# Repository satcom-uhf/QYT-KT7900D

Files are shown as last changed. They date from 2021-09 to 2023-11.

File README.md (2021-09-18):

# QYT KT7900D ([RU](README_RU.md))

Qyt KT7900D is very tiny and cheap radio. Recommended for beginners.



## [Modified software](https://github.com/satcom-uhf/QYT-KT7900D/releases/tag/Software)

## [IOR channels](https://github.com/satcom-uhf/QYT-KT7900D/releases/tag/Channels72E)
## [Remote control adapter](RemoteControl/README.md)

## [Activity indicator](ActivityIndicator/README.md)

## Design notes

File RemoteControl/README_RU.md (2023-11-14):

# Адаптер для удаленного управления QYT-KT7900D ([EN](README.md))

Адаптер позволяет программно нажимать на кнопки передней панели станции через последовательный порт. Это может быть полезно для тесной интеграции с каким-либо сторонним ПО (например Telegram Bot).  Поддерживаемые команды:

- ```+``` "Вверх"
- ```-``` "Вниз"
- ```e``` "Exit/ABCD"
- ```m``` "Menu"
- ```t``` Включает передачу
- ```s``` Выключает передачу

Данного набора команд достаточно чтобы программно изменить большинство настроек станции или выбрать нужный канал (каналы)

### Компоненты

- [Arduino Nano](https://docs.arduino.cc/hardware/nano)
- [PC817 x 4](https://www.farnell.com/datasheets/73758.pdf)
- 4 резистора 220 Ом
- 3 резистора 1К
- тонкие провода
- разьем 7 или 8 пинов
- макетная плата
- Коннектор RJ45 
- какой-нибудь мелкий MOSFET (я взял с дохлой батареи ноута)

### Инструменты

- Паяльник =)
- [Fritzing](https://github.com/fritzing/fritzing-app/releases) чтобы посмотреть файл схемы [RemoteControl.fzz](https://github.com/satcom-uhf/QYT-KT7900D/blob/main/RemoteControl/RemoteControl.fzz)
- [Arduino IDE](https://www.arduino.cc/en/software) чтобы скомпилировать и загрузить скетч [RemoteControl.ino](https://github.com/satcom-uhf/QYT-KT7900D/blob/main/RemoteControl/RemoteControl.ino) в Arduino

## Схема
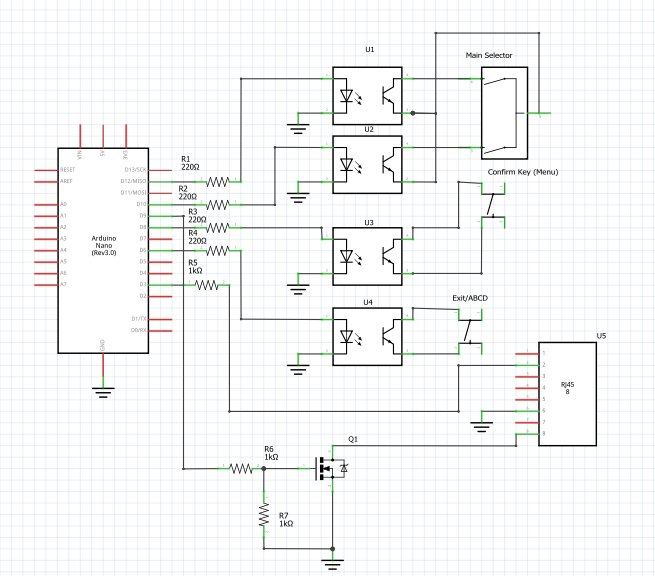
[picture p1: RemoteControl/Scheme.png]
Scheme


### Шаг 1. Смонтируйте и припаяйте все копоненты на плату согласно схеме
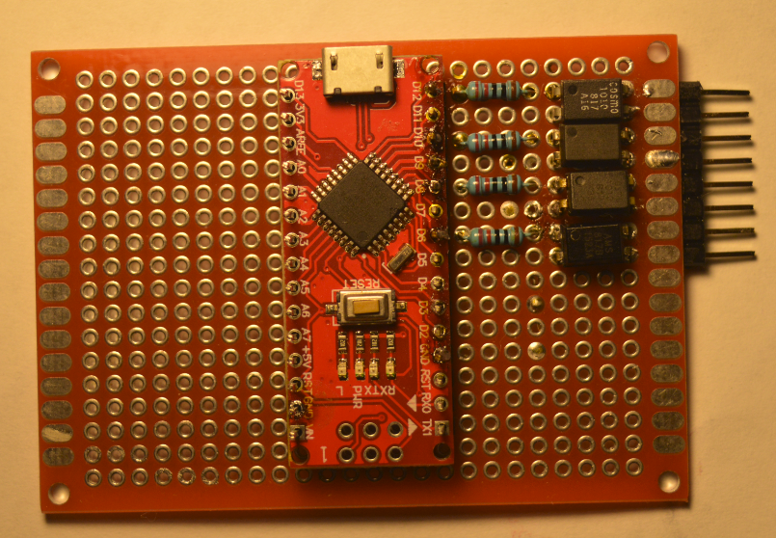
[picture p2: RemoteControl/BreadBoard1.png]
Board1

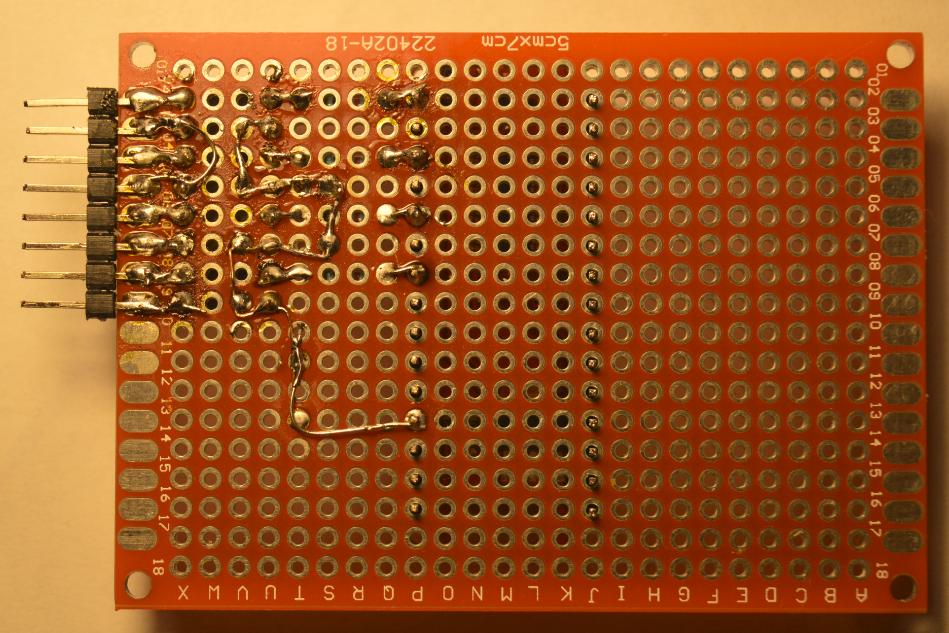
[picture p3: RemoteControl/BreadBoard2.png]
Board2


### Шаг 2. Откройте прошивку  [RemoteControl.ino](https://github.com/satcom-uhf/QYT-KT7900D/blob/main/RemoteControl/RemoteControl.ino) с помощью Arduino IDE и загрузите ее в Arduino Nano
### Шаг 3. Снимите переднюю панель и подключите провода к указанным точкам

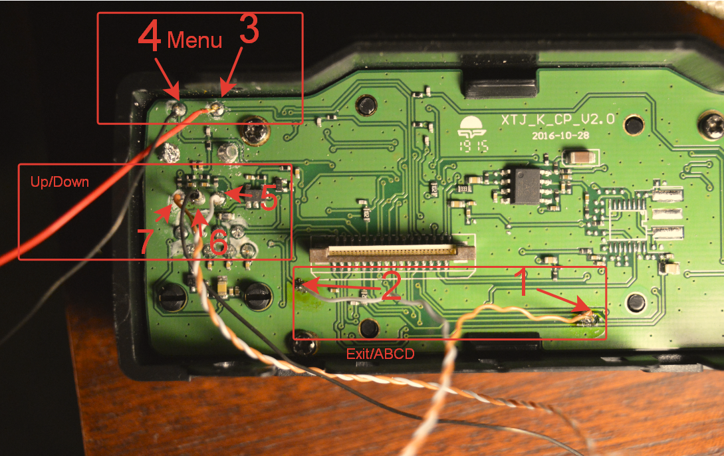
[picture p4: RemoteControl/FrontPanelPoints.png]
ConnectionPoints

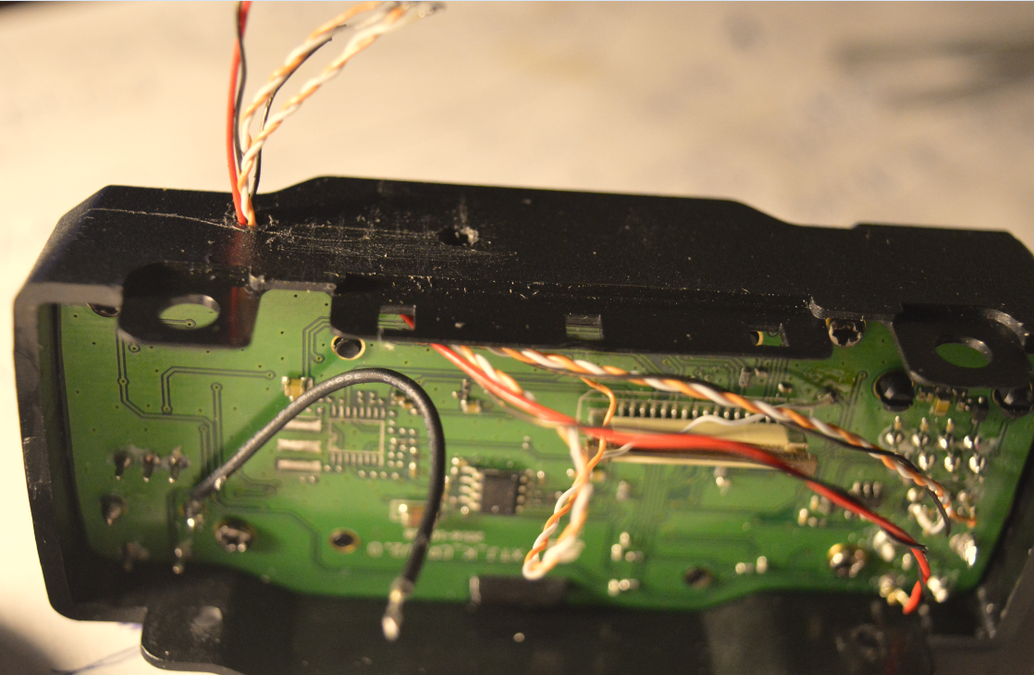
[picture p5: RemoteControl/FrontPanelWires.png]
Wires

### Шаг 4. Приклейте разьем суперклеем
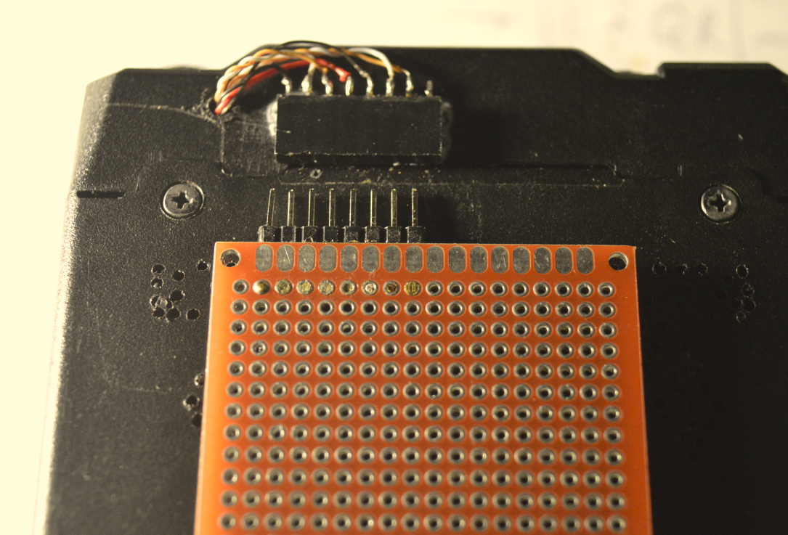
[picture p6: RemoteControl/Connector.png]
Connector


### Шаг 5. Подключите адаптер
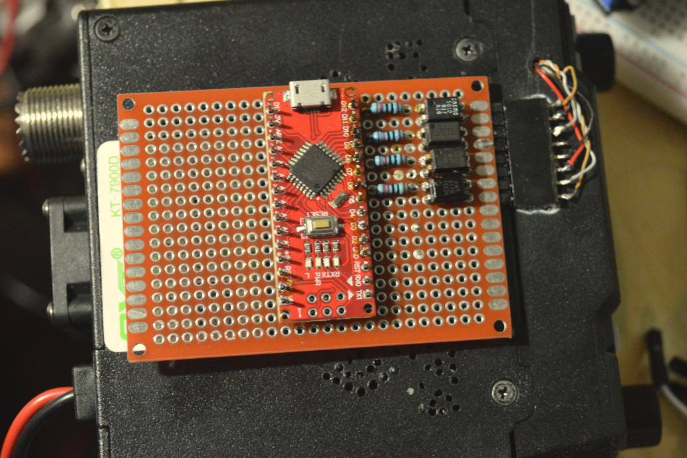
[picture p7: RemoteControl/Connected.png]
Connected

 Готово!

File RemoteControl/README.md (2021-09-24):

# Remote control adapter for QYT-KT7900D ([RU](README_RU.md))

The remote control adapter allows pressing buttons on the front panel programmatically via serial port. It can be useful for deep integration with any kind of software (i.e. Telegram Bot).  The following commands are supported:

- ```+``` is equal to "Up"
- ```-``` is equal to "Down"
- ```e``` is equal to "Exit/ABCD"
- ```m``` is equal to "Menu"
- ```t``` enables PTT (be careful!)
- ```s``` disables PTT

This command set is enough to change the most of settings and select any channels.
### Components required
- [Arduino Nano](https://docs.arduino.cc/hardware/nano)
- [PC817 x 4](https://www.farnell.com/datasheets/73758.pdf)
- 4 resistors 220 Ohms
- 3 resistors 1K
- wires
- connector (7 or 8 pins)
- bread board
- RJ45 connector
- any small MOSFET
  
### Tools required

- Soldering iron =)
- [Fritzing](https://github.com/fritzing/fritzing-app/releases) to view/edit the scheme (RemoteControl.fzz)
- [Arduino IDE](https://www.arduino.cc/en/software) to compile/upload sketch (RemoteControl.ino) to your Arduino board

Scheme

### Step 1. Mount and solder all components on the board
Board1
Board2

### Step 2. Open  RemoteControl.ino using Arduino IDE and upload it to Arduino Nano
### Step 3. Remove the front panel and connect the wires to the following points

ConnectionPoints
Wires
### Step 4. Glue the connector with superglue
Connector

### Step 5. Connect the module
Connected

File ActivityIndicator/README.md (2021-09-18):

# Activity indicator ([RU](README.md))

It's just a LED indicates squelch state. Just use signal from pin 2 and invert it:

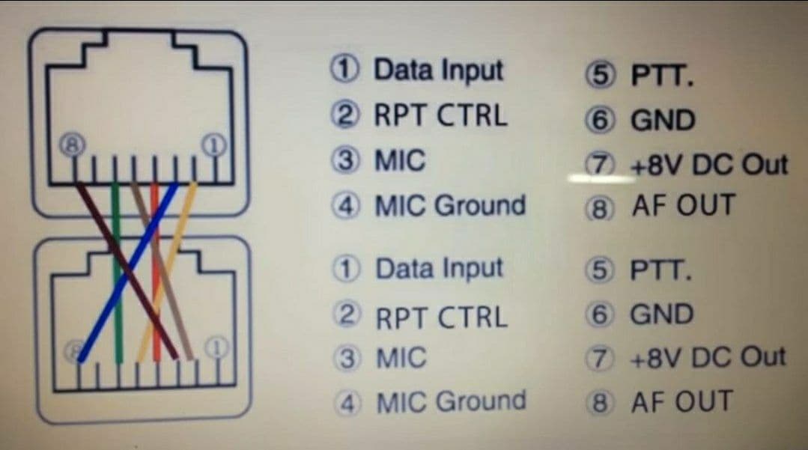
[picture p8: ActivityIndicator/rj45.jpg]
rj45


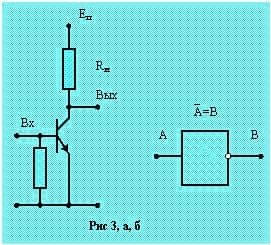
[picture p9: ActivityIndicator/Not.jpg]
not


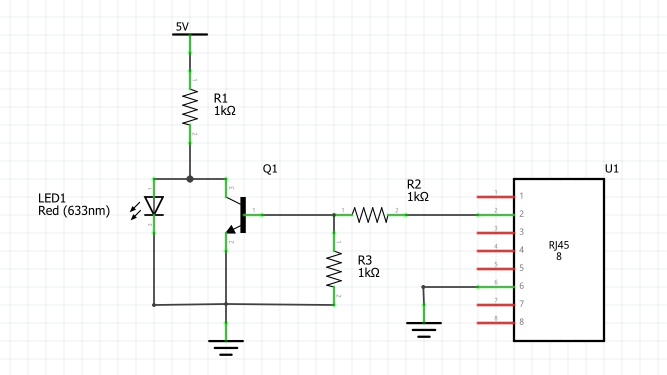
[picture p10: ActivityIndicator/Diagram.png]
diagram


## Components

- NPN transistor (i.e. 2222)
- 3 resistors 1k
- LED

## Step 1

Unmount PTT front panel and drill a hole for LED

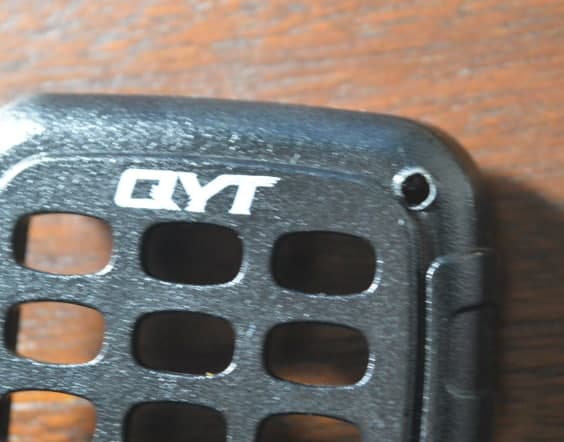
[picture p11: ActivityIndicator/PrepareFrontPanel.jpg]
PrepareFrontPanel


## Step 2

Look for a hidden cut wire from the second pin of RJ45

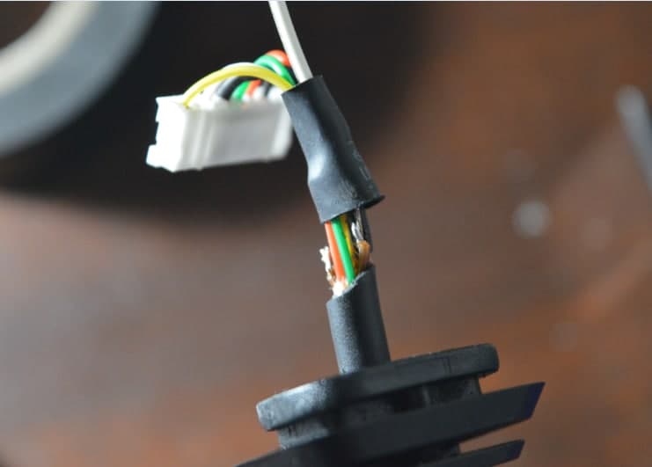
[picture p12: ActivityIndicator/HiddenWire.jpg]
hidden


## Step 3

Make it longer

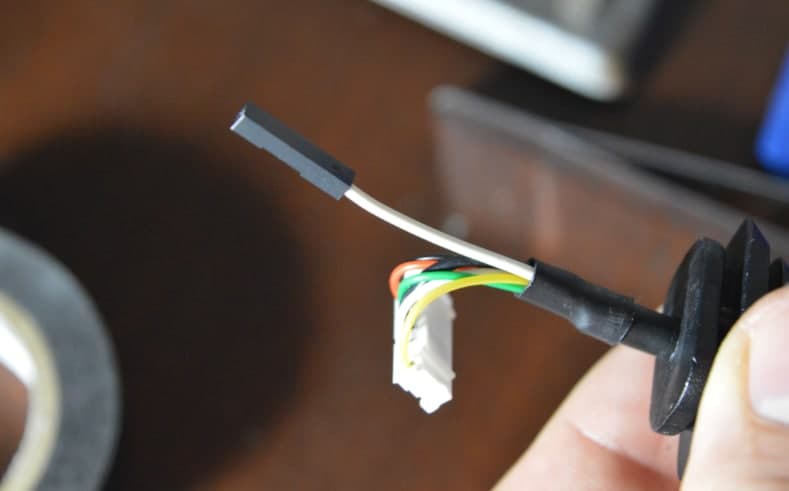
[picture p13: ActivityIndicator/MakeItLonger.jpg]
LongerWire


## Step 4

Mount components

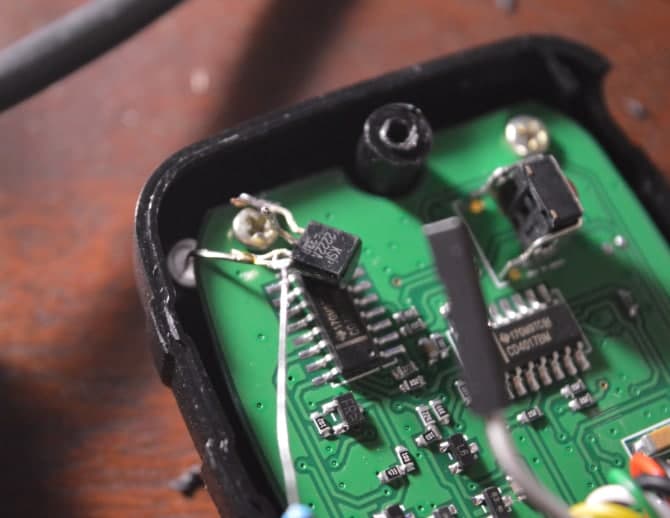
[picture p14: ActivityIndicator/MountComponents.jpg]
components


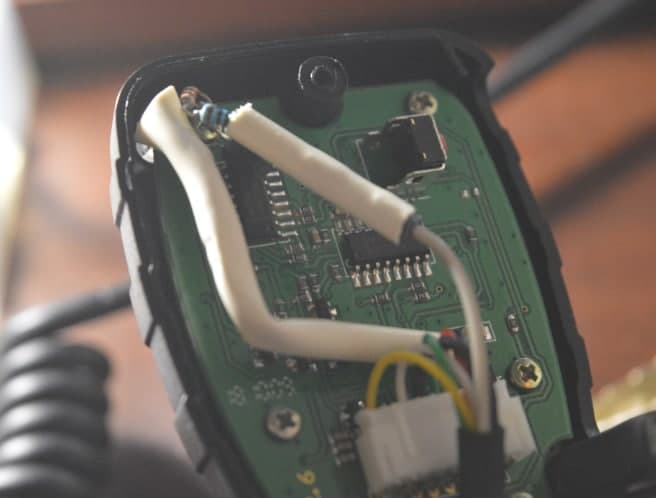
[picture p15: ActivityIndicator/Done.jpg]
done


## Step 5

Enable REP-M mode and test it:

No activity

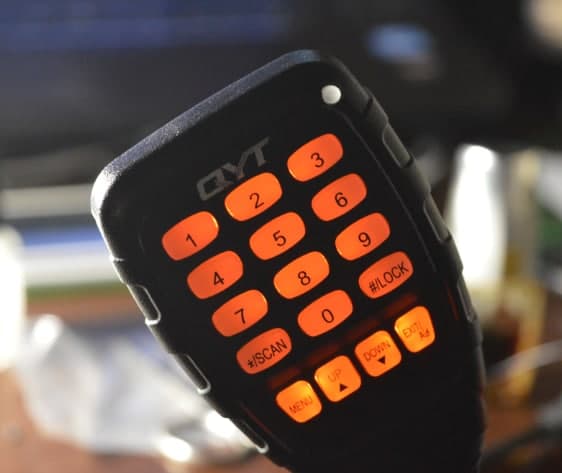
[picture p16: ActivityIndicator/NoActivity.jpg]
No Activity


Someone on the air

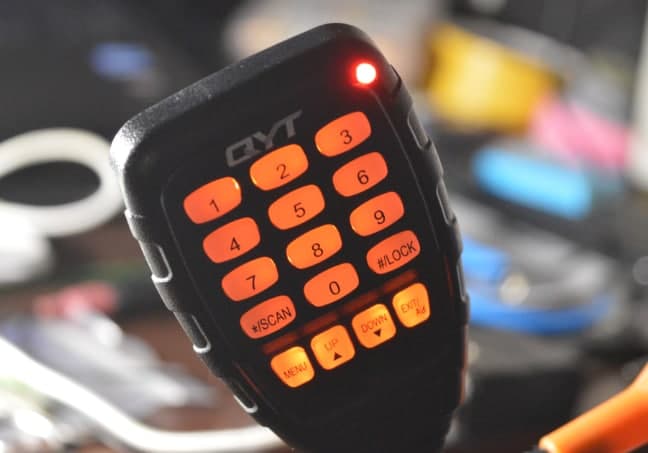
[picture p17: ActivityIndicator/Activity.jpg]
Activity


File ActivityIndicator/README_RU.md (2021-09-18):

# Индикатор активности ([EN](README.md))

Это просто светодиод, который светится при открытии шумодава. Нужно лишь инвертировать сигнал, поступающий со второго пина:

rj45

not

diagram

## Компоненты

- NPN транзистор (i.e. 2222)
- 3 резистора 1К
- светодиод

## Шаг 1

Разберите тангенту и просверлите отверстие для светодиода

PrepareFrontPanel

## Шаг 2

Под термоусадкой найдите скрытый обрезанный провод от пина 2

hidden

## Шаг 3

Удлините провод

LongerWire

## Шаг 4

Смонтируйте компоненты согласно схеме

components

done

## Step 5

В меню станции включите режим REP-M и проверьте работоспособность индикатора:

Шумодав закрыт

No Activity

Активность в эфире, шумодав открыт

Activity

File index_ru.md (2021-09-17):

# QYT KT7900D ([EN](index.md))

Qyt KT7900D маленькое дешевое и простое радио. Отличный вариант для начинающих.



## [Крякнутый софт](https://github.com/satcom-uhf/QYT-KT7900D/releases/tag/Software)

## [Адаптер для удаленного управления](RemoteControl/README_RU.md)

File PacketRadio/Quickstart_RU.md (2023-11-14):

# [Пакетное радио](https://etnowiki.ru/wiki/Packet_radio) на коленке

<video src="https://user-images.githubusercontent.com/90838159/282679990-01b05537-150c-46a9-a750-b3de58aedcb6.mp4" data-canonical-src="https://user-images.githubusercontent.com/90838159/282679990-01b05537-150c-46a9-a750-b3de58aedcb6.mp4" controls="controls" muted="muted" class="d-block rounded-bottom-2 border-top width-fit" style="max-height:640px; min-height: 200px"></video>

В данной статье мы рассмотрим как организовать пакетную связь доступными средствами. Для приема и передачи сигнала будет использован трансивер Qyt KT-7900D. Преобразовывать текст в звуковой сигнал и обратно будет компьютер под управлением Windows.

## Программное обеспечение
- Модем от UZ7HO [SoundModem](http://uz7.ho.ua/modem_beta/soundmodem113.zip) 
- Терминал от UZ7HO [EasyTerm](http://uz7.ho.ua/apps/easyterm49.zip)

## Коммутация между трансивером и ПК
Общая схема приблизительно такая:

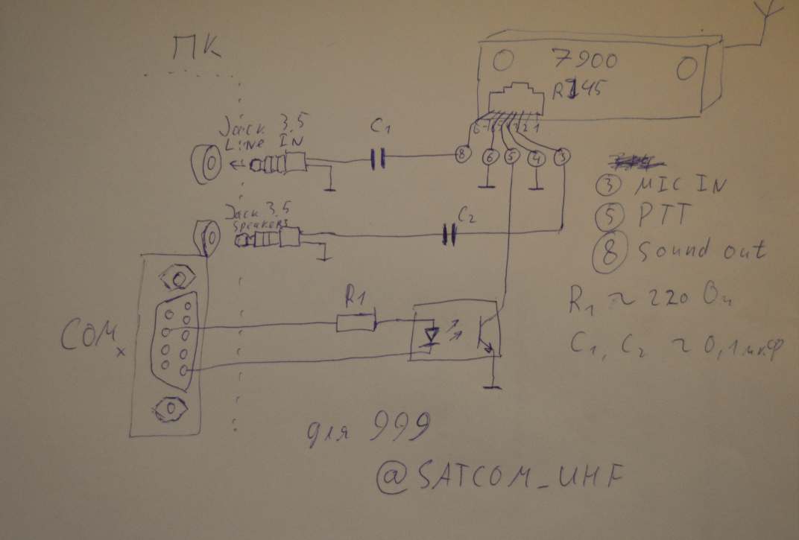
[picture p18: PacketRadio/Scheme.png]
scheme


Звуковой выход трансивера (у Qyt он выведен на 8м пине RJ45) мы подключаем к линейному входу звуковой карты ПК. Звуковой выход компьютера подключаем к микрофонному входу трансивера (у Qyt он выведен на 3й пин RJ45). Для развязки по постоянному применены конденсаторы. Для полной гальванической развязки можно применить трансформаторы.

Простейший способ позволить SoundModem переходить из режима приема в режим передачи - это указать COM-порт, к которому подключен ваш трансивер. SoundModem использует 7й пин (RTS) для активации PTT. В качестве коммутирующего элемента можно использовать оптопару с резистором (как на схеме), или сделать ключ на каком-нибудь MOSFETе. 

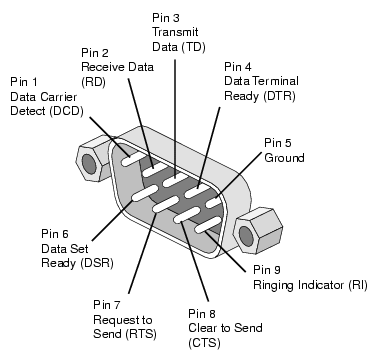
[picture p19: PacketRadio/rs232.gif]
rs232
 

 Если на вашем ПК отсутствует аппаратный COM-порт, вы можете использовать USB-COM переходник.

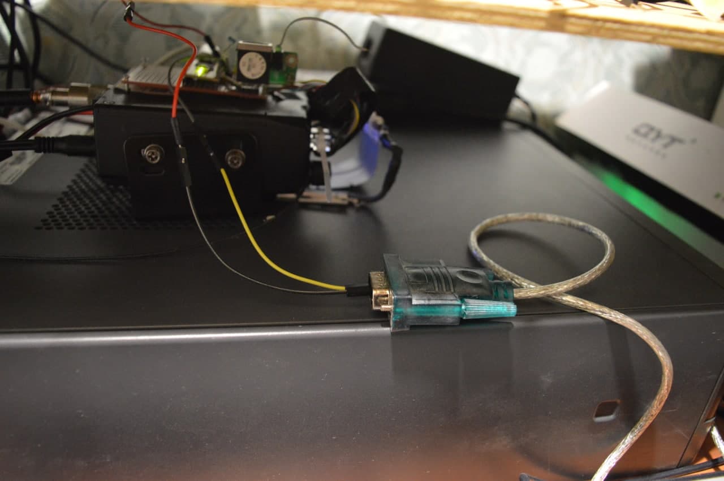
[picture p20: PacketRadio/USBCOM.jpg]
usbcom


## Настройка приемной части

1. Подключите звуковой выход станции к линейному входу ПК. У Qyt есть особенность: чтобы звуковой сигнал появился на пине 8 в меню станции необходимо выбрать пункт REP-M и установить там значение Carrier.
2. Установите линейный вход устройством записи по умолчанию

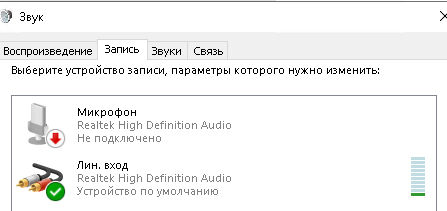
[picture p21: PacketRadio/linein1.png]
line1


3. Настройте уровень сигнала таким образом, чтобы не было "перегруза"

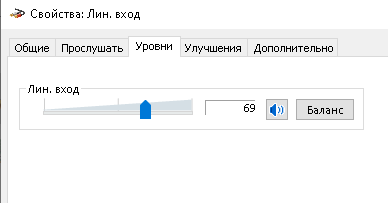
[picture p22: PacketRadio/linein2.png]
line2


4. Распакуйте и запустите [SoundModem](http://uz7.ho.ua/modem_beta/soundmodem113.zip) 
5. Откройте меню настроек Settings->Devices и убедитесь, что для ввода и вывода звука выбраны верные входы и выходы. Также выберите COM порт, к которому подключен ваш трансивер

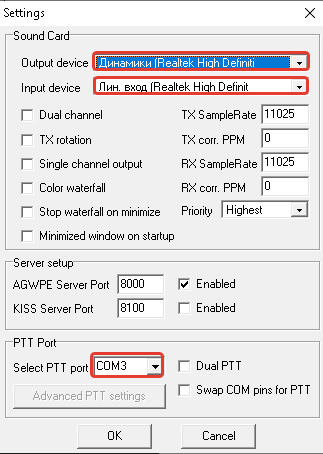
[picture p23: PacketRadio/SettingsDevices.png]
SettingsDevices


6. Убедитесь, что траффик, который вы принимаете от BBS, успешно демодулируется

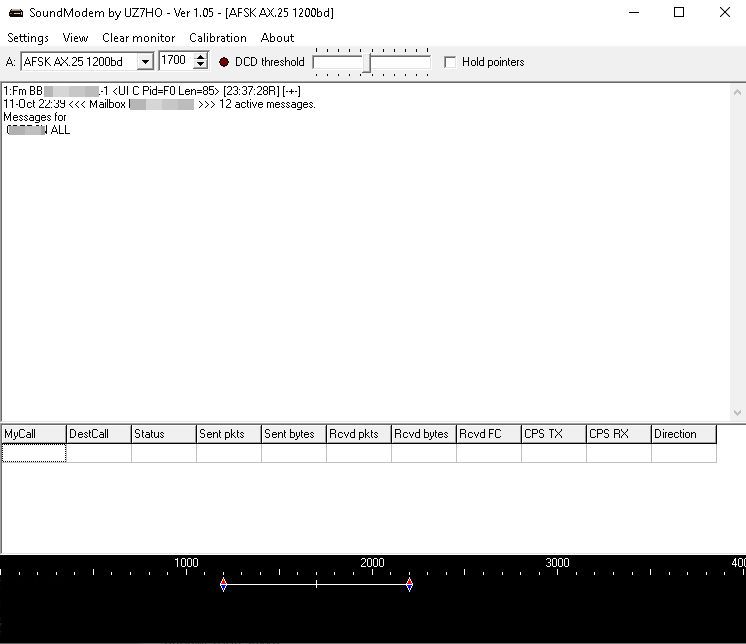
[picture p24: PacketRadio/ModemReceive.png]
Receive


## Настройка передающей части

1. Убедитесь, что звуковой выход ПК подключен к микрофонному входу станции
2. Убедитесь, что SoundModem запущен. В настройках Settings->Modems  рекомендуется установить значение параметра TXDelay таким образом, чтобы компенсировать задержку радиостанции на переход в режим передачи. У меня это значение равно 400.

TXDelay

3. Установите громкость воспроизведения близкой к минимальной
   
   volume

4. Распакуйте и запустите [EasyTerm](http://uz7.ho.ua/apps/easyterm49.zip) В окне терминала нажмите "Connect".
5. В появившемся диалоге укажите ваш позывной и позывной узла, с которым хотите соединиться.Еще раз нажмите "Connect".
   
Connect

6. Вуаля! Дальше вы можете общаться текстовыми командами с узлом, к которому подключились.
   
Connected

## PS

Выражаю огромную благодарность [UZ7HO](http://uz7.ho.ua/packetradio.htm) за труды по созданию ПО для Windows. На его [официальной страничке](http://uz7.ho.ua/packetradio.htm) так же можно скачать ПО для игры в [шахматы](http://uz7.ho.ua/apps/chess10.zip) и [шашки](http://uz7.ho.ua/apps/checkers6.zip).

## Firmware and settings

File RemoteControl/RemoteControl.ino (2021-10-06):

#define VALCODER_UP 12
#define VALCODER_DOWN 10
#define MENU 8
#define ABCD 6
#define PTT 9
#define SQUELCH_OPEN 3
#define EXTERNAL_PTT 7
bool valcoderState = false;
bool extPttState = false;
void setup(void)
{
   pinMode(PTT, OUTPUT);
   digitalWrite(PTT, LOW);
   pinMode(VALCODER_UP, OUTPUT);
   pinMode(VALCODER_DOWN, OUTPUT);
   pinMode(MENU, OUTPUT);
   pinMode(ABCD, OUTPUT);
   Serial.begin(9600);
   pinMode(SQUELCH_OPEN, INPUT);
   pinMode(EXTERNAL_PTT, INPUT);
   attachInterrupt(digitalPinToInterrupt(SQUELCH_OPEN), monitorActivity, CHANGE);
}

void monitorActivity()
{
   if (digitalRead(SQUELCH_OPEN) == LOW)
   {
      digitalWrite(LED_BUILTIN, HIGH);
      Serial.println("activity");
   }
   else
   {
      digitalWrite(LED_BUILTIN, LOW);
      Serial.println("silence");
   }
}

void clickButton(int pin)
{
   digitalWrite(pin, HIGH);
   delay(15);
   digitalWrite(pin, LOW);
}

void valCoderTick(int pin1, int pin2)
{
   valcoderState = !valcoderState;
   digitalWrite(pin1, valcoderState);
   delay(5);
   digitalWrite(pin2, valcoderState);
}

void up()
{
   valCoderTick(VALCODER_DOWN, VALCODER_UP);
}
void down()
{
   valCoderTick(VALCODER_UP, VALCODER_DOWN);
}

void ptt()
{
   digitalWrite(PTT, HIGH);
   Serial.println("PTT");
}
void stopPtt()
{

   digitalWrite(PTT, LOW);
   Serial.println("PTTSTOP");
}

void loop()
{
   byte ch;
   bool extPtt = digitalRead(EXTERNAL_PTT);
   if (extPtt != extPttState)
   {
      extPttState = extPtt;
      if (extPtt)
      {
         ptt();
      }
      else
      {
         stopPtt();
      }
   }

   if (Serial.available())
   {
      ch = Serial.read();
      switch (ch)
      {
      case '+':
         up();
         Serial.println("Up");
         break;
      case '-':
         down();
         Serial.println("Down");
         break;
      case 'e':
         clickButton(ABCD);
         Serial.println("ABCD");
         break;
      case 'm':
         clickButton(MENU);
         Serial.println("MENU");
         break;
      case 't':
         ptt();
         break;
      case 's':
         stopPtt();
         break;
      }
   }
}

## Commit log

2021-09-16 Arduino sketch
2021-09-16 Readme rus
    [RemoteControl.fzz]
2021-09-18 Activity indicator
    [ActivityIndicator.fzz]
2021-09-24 forgot mosfet
    [RemoteControl.fzz]
